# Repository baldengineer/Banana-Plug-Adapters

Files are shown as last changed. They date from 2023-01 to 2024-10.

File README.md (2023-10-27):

Banana jack (4mm, 19mm) to USB-A Adapter Banana (4mm) to USB-A

These adpaters let you plug common power types into a bench power supply. They require a little bit of caution on your side. For example, don't apply 9 volts to the USB adapter!

Each adapter is two pieces made from a single PCB. The part that holds the banana plugs inserts into the adapter part. Then you solder them together. 

## To use them.
* One pack of [Ponoma 72918 4mm banana plug](https://octopart.com/72918-pomona+electronics-585505?r=sp). 
* Break off the two M3 holes
* Use the tabs to solder them together at 90 degrees
* Optional, add LED with current limiting resistor. 
* Optional, clamping diode.
* Plug into power supply. :)

## Discuss on Discord
Join the [AddOhms/Baldengineer Discord](https://discord.gg/Q3xzyuWqm6) to discuss this project.

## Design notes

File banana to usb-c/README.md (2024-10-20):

# Banana Plug to USB-C (Power Only) Adapter

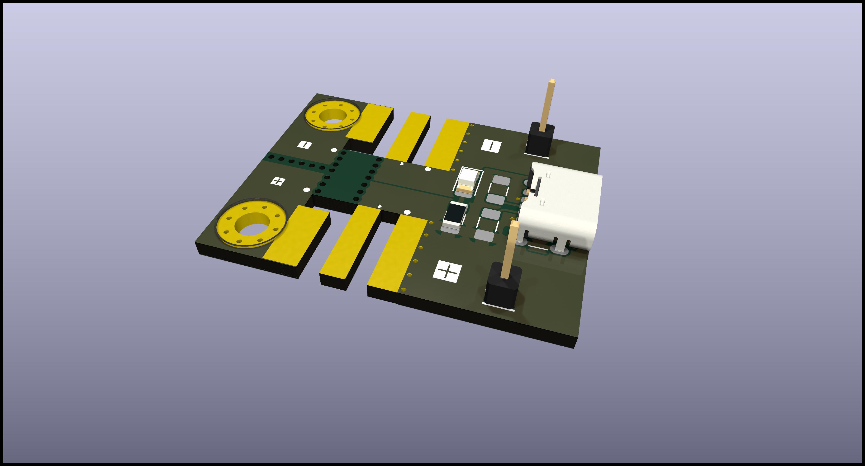
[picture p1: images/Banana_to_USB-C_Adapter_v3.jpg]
usb-c v3


Based on the `USB4125-GF-A` 6 position surface mount connector.

## Version 3: DFP Fix
Version 2 had placements for pull-down resistors. As the DFP, this board should have pull-up resistors. Turns out, most UFP devices don't care so v2 works fine in most cases.

### Status
2024-OCT-20: V3 has not been tested yet.

## DFP Pull-Up Values
| **DFP Advertisement** | **R Pull-Up to 4.75 - 5.5 V** | **R Pull-Up to 3.3 ±5%** |
| :--- | :---: | :---: |
| **Default USB PWR** | 56 kΩ ± 20% | 36 kΩ ± 20% |
| **1.5 A at 5 V** | 22 kΩ ± 5%  | 12 kΩ ± 5% |
| **3.0 A at 5V** | 10 kΩ ± 5% | 4.7 kΩ ± 5% |

[Values from Infineon KB Article](https://community.infineon.com/t5/Knowledge-Base-Articles/USB-Type-C-connector-Rp-Rd-and-Ra-termination-resistors/ta-p/253544)

## Discuss on Discord
Join the [AddOhms/Baldengineer Discord](https://discord.gg/Q3xzyuWqm6) to discuss this project

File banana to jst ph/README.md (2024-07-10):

Banana Plug to JST PH Adapter

This adapter is intended to support Adafruit-style LiPo battery connections for use on a SMU or electronic load.

(You could probably also use the adapter to recondition a LiPo below its minimum safe voltage.)

## PCB Status
Work in-progress: waiting for board to come back from fab.

## Discuss on Discord
Join the [AddOhms/Baldengineer Discord](https://discord.gg/Q3xzyuWqm6) to discuss this project

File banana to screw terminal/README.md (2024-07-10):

Banana Plug to Screw Terminal Adapter Adapter

Based on a (mostly) generic 5.08mm pitch screw terminal

## Discuss on Discord
Join the [AddOhms/Baldengineer Discord](https://discord.gg/Q3xzyuWqm6) to discuss this project

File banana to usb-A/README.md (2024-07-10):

Banana jack (4mm, 19mm) to USB-A Adapter Banana (4mm) to USB-A

## Banana to USB-A Adapter
* Connect USB-A devices to a bench power supply.
* Intended to be used with [Ponoma 72918 banana plug](https://octopart.com/72918-pomona+electronics-585505?r=sp). Break off the two M3 holes, use the tabs to solder them together at 90 degrees, and plug into power supply.
* Rev 1 project link on [OSH Park](https://oshpark.com/shared_projects/gjQOWRep).
* Rev 2 project link on [OSH Park](https://oshpark.com/shared_projects/TIto0uSf).

See root page for instructions on how to use them.

## Discuss on Discord
Join the [AddOhms/Baldengineer Discord](https://discord.gg/Q3xzyuWqm6) to discuss this project

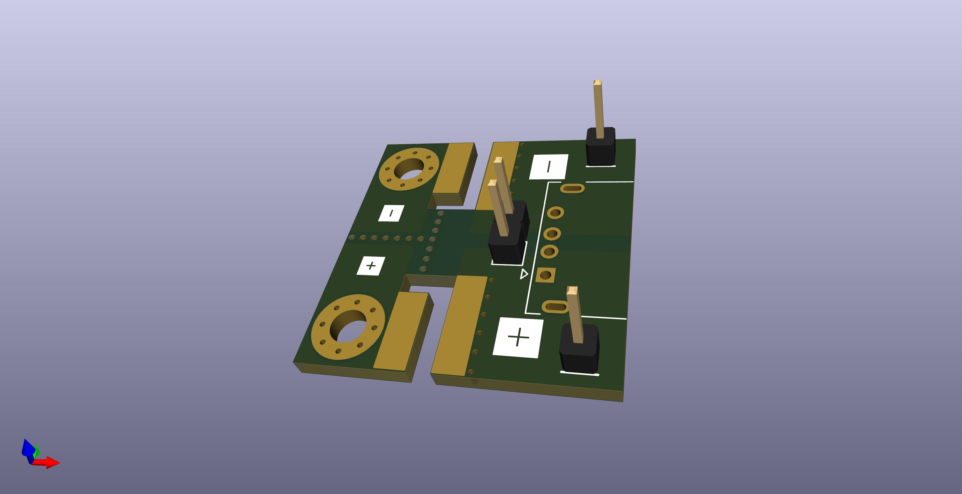
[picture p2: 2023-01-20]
images/Banana_to_USB_Adapter_rev1.jpg

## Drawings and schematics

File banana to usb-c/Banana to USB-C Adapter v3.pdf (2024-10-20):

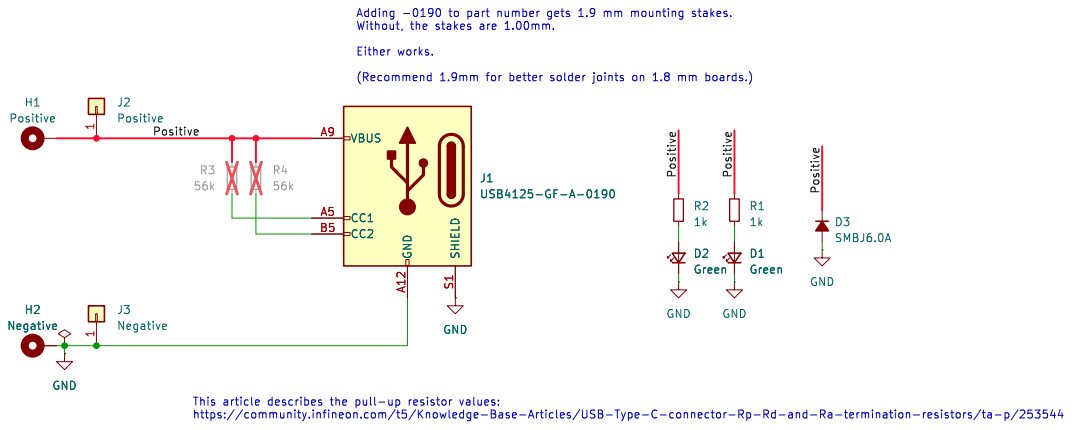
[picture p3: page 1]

Id: 1/1 Title: Banana to USB-C Adapter (Power Only) File: Banana to USB-C Adapter v3.kicad_sch Sheet: / baldengineer.com

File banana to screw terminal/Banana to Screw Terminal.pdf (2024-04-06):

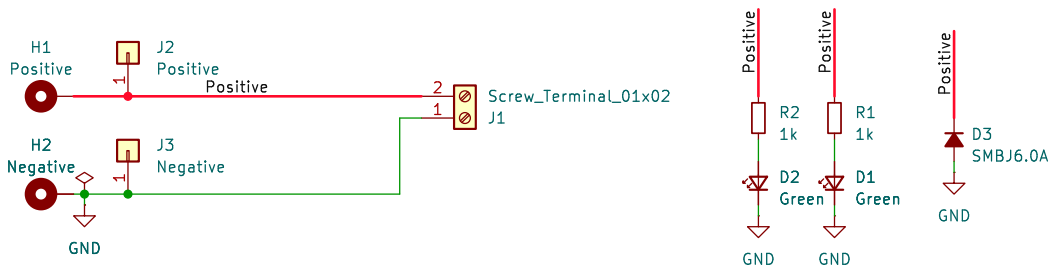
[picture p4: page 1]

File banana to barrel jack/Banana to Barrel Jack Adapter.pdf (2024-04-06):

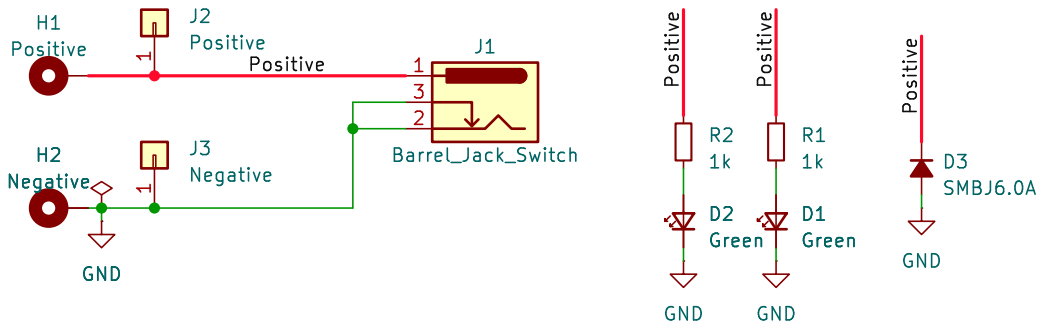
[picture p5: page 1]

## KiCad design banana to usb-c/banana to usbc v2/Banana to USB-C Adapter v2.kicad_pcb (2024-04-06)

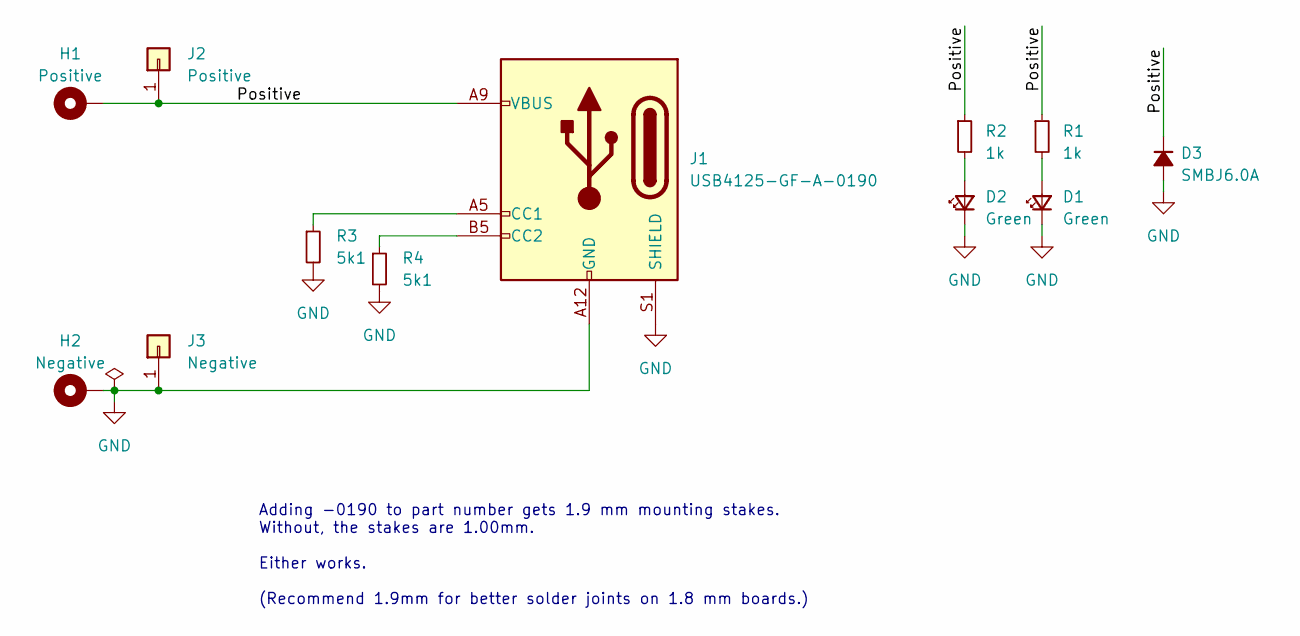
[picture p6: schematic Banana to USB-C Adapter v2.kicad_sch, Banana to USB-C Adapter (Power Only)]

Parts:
D1, D2: Green; LED_1206_3216Metric_Pad1.42x1.75mm_HandSolder
D3: SMBJ6.0A; D_SMA-SMB_Universal_Handsoldering
H1: Positive; MountingHole_3.2mm_M3_Pad_Via
H2: Negative; MountingHole_3.2mm_M3_Pad_Via
J1: USB4125-GF-A-0190; USB_C_Receptacle_GCT_USB4125-xx-x_6P_TopMnt_Horizontal
J2: Positive; PinHeader_1x01_P2.54mm_Vertical
J3: Negative; PinHeader_1x01_P2.54mm_Vertical
R1, R2: 1k; R_1206_3216Metric_Pad1.30x1.75mm_HandSolder
R3, R4: 5k1; R_1206_3216Metric_Pad1.30x1.75mm_HandSolder

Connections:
/Positive: D3.1 (K), H1.1, J1.A9 (VBUS), J1.B9 (VBUS), J2.1, R1.1, R2.1
GND: D1.1 (K), D2.1 (K), D3.2 (A), H2.1, J1.A12 (GND), J1.B12 (GND), J1.S1 (SHIELD), J3.1, R3.2, R4.2
unnamed: D1.2 (A), R1.2
unnamed: D2.2 (A), R2.2
unnamed: J1.A5 (CC1), R3.1
unnamed: J1.B5 (CC2), R4.1

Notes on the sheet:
Adding -0190 to part number gets 1.9 mm mounting stakes. Without, the stakes are 1.00mm. Either works. (Recommend 1.9mm for better solder joints on 1.8 mm boards.)

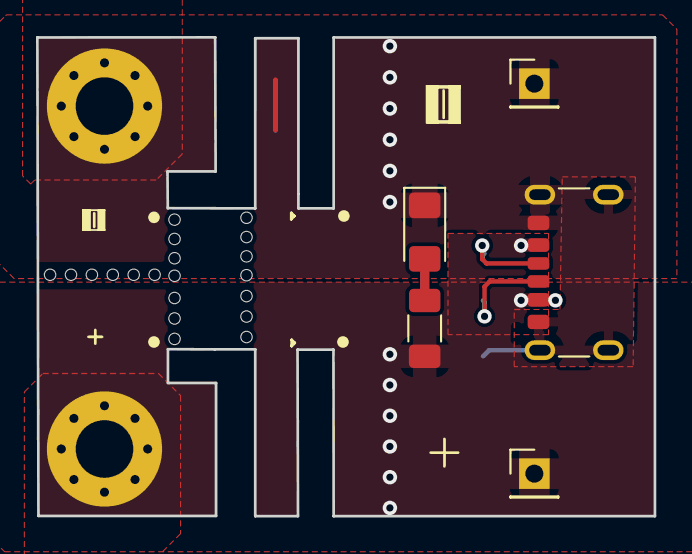
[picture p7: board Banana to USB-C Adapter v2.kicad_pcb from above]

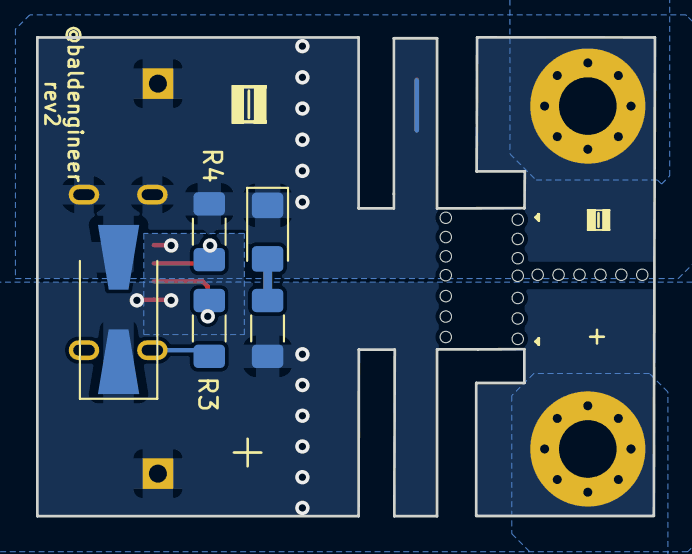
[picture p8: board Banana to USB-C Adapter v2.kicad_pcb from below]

Board: 2 copper layers, 34.3 x 26.6 mm, 12 parts (5 on the bottom side), 6 nets.

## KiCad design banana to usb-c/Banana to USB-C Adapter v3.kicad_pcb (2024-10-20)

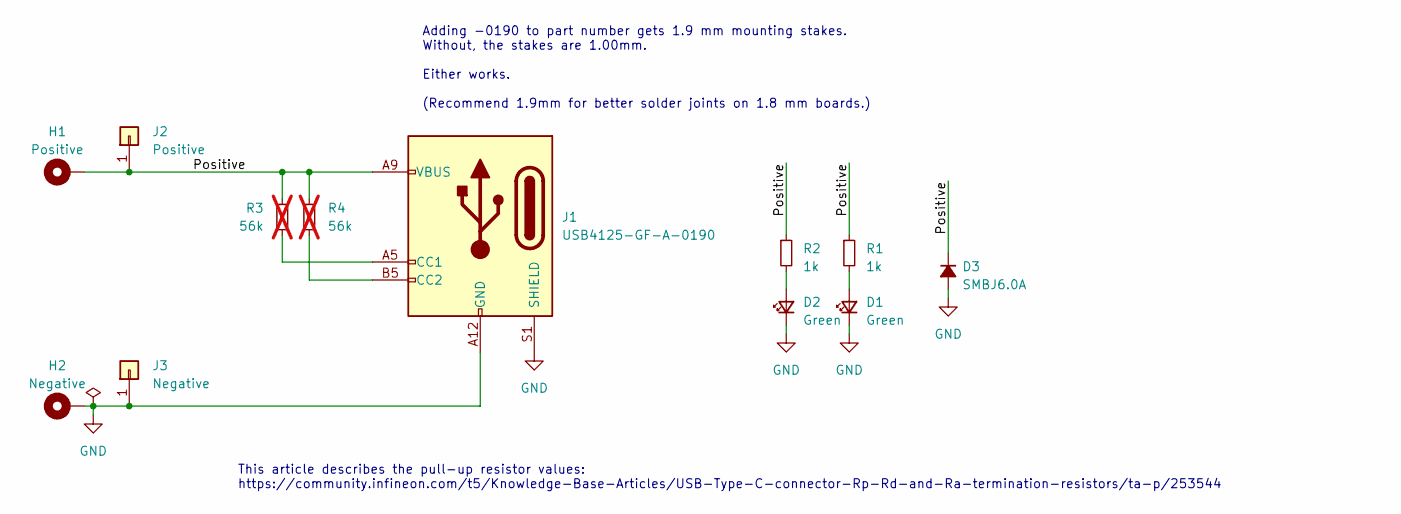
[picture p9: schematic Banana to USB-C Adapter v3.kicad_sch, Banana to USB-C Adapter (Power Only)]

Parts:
D1, D2: Green; LED_1206_3216Metric_Pad1.42x1.75mm_HandSolder
D3: SMBJ6.0A; D_SMA-SMB_Universal_Handsoldering
H1: Positive; MountingHole_3.2mm_M3_Pad_Via
H2: Negative; MountingHole_3.2mm_M3_Pad_Via
J1: USB4125-GF-A-0190; USB_C_Receptacle_GCT_USB4125-xx-x_6P_TopMnt_Horizontal
J2: Positive; PinHeader_1x01_P2.54mm_Vertical
J3: Negative; PinHeader_1x01_P2.54mm_Vertical
R1, R2: 1k; R_1206_3216Metric_Pad1.30x1.75mm_HandSolder
R3, R4: 56k; R_1206_3216Metric_Pad1.30x1.75mm_HandSolder; not fitted

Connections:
/Positive: D3.1 (K), H1.1, J1.A9 (VBUS), J1.B9 (VBUS), J2.1, R1.1, R2.1, R3.1, R4.1
GND: D1.1 (K), D2.1 (K), D3.2 (A), H2.1, J1.A12 (GND), J1.B12 (GND), J1.S1 (SHIELD), J3.1
unnamed: D1.2 (A), R1.2
unnamed: D2.2 (A), R2.2
unnamed: J1.A5 (CC1), R3.2
unnamed: J1.B5 (CC2), R4.2

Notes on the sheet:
Adding -0190 to part number gets 1.9 mm mounting stakes. Without, the stakes are 1.00mm. Either works. (Recommend 1.9mm for better solder joints on 1.8 mm boards.)
This article describes the pull-up resistor values: https://community.infineon.com/t5/Knowledge-Base-Articles/USB-Type-C-connector-Rp-Rd-and-Ra-termination-resistors/ta-p/253544

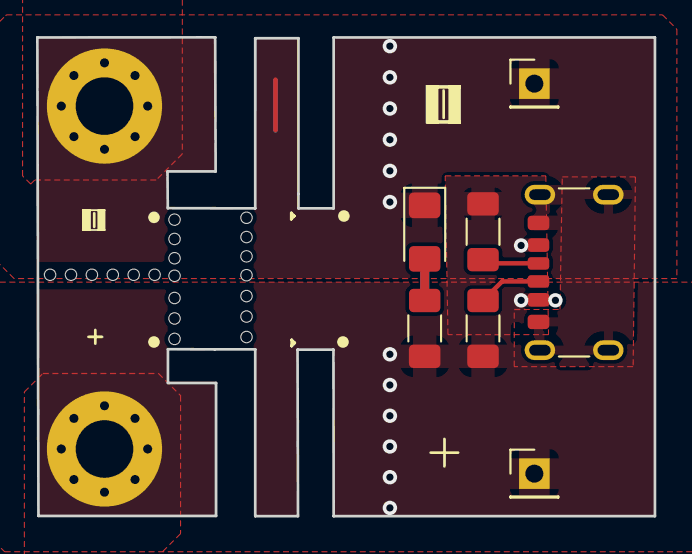
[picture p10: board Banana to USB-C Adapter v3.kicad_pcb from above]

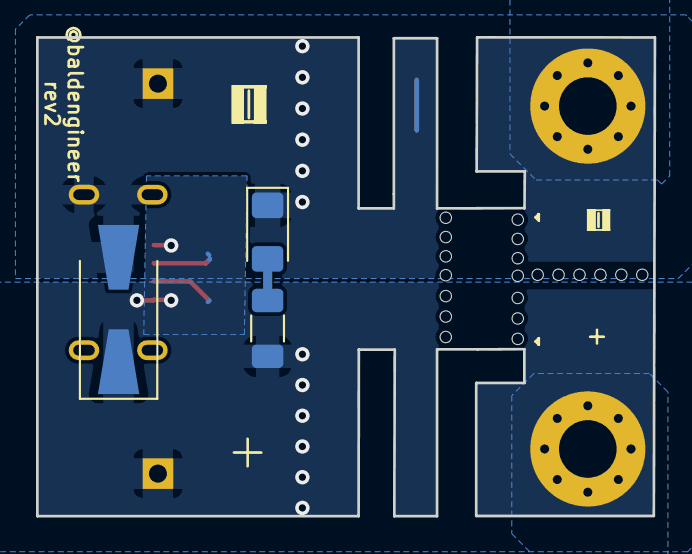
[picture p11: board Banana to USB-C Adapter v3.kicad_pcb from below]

Board: 2 copper layers, 34.3 x 26.6 mm, 12 parts (3 on the bottom side), 6 nets.

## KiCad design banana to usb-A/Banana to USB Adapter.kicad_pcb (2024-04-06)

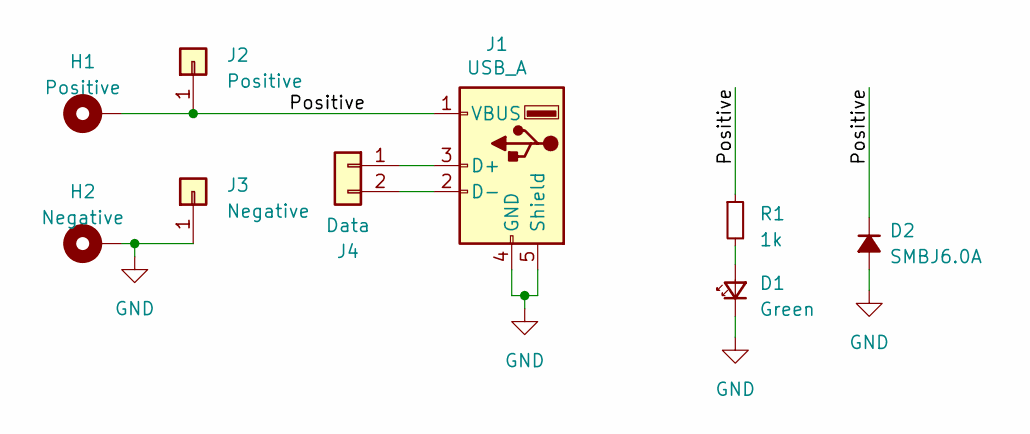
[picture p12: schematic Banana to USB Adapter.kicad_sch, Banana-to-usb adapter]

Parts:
D1: Green; LED_1206_3216Metric_Pad1.42x1.75mm_HandSolder
D2: SMBJ6.0A; D_SMA-SMB_Universal_Handsoldering
H1: Positive; MountingHole_3.2mm_M3_Pad_Via
H2: Negative; MountingHole_3.2mm_M3_Pad_Via
J1: USB_A; USB_A_GCT_USB1125; MPN USB1125-GF-B
J2: Positive; PinHeader_1x01_P2.54mm_Vertical
J3: Negative; PinHeader_1x01_P2.54mm_Vertical
J4: Data; PinHeader_1x02_P2.54mm_Vertical
R1: 1k; R_1206_3216Metric_Pad1.30x1.75mm_HandSolder

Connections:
/Positive: D2.1 (K), H1.1, J1.1 (VBUS), J2.1, R1.1
GND: D1.1 (K), D2.2 (A), H2.1, J1.4 (GND), J1.5 (Shield), J3.1
unnamed: D1.2 (A), R1.2
unnamed: J1.3 (D+), J4.1
unnamed: J1.2 (D-), J4.2

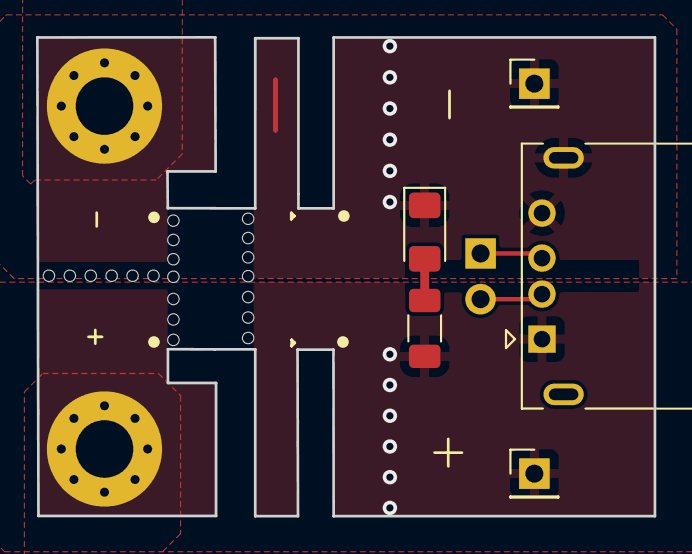
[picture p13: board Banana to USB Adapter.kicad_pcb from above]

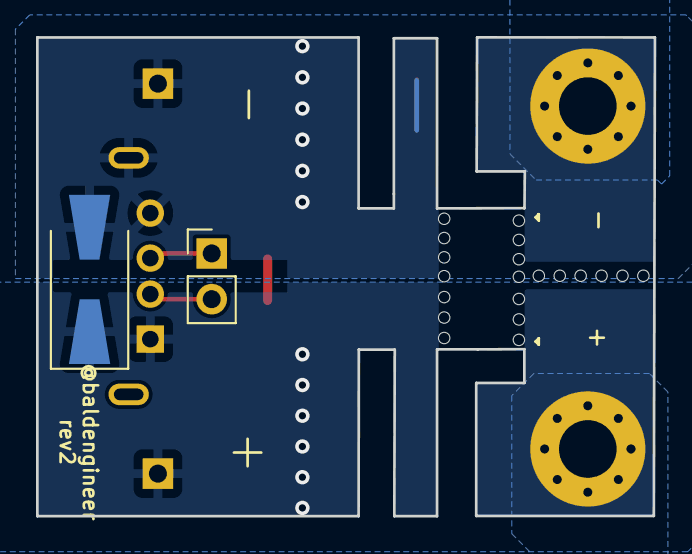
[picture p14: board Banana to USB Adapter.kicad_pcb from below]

Board: 2 copper layers, 34.3 x 26.6 mm, 9 parts (2 on the bottom side), 5 nets.

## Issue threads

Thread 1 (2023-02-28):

R1: +V and GND are backwards

baldengineer, 2023-02-28:
Minor important, but the nodes for +V and GND are backward on the Host (USB-A) connector.

¯\_(ツ)_/¯

baldengineer, 2023-02-28:
Actually... the PCB is fine. There's an issue with assembly, will open new issue.

Closed 2023-02-28.

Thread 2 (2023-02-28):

R1: Need to extend pads

baldengineer, 2023-02-28:
The pads on the screw hole side should be extended. That way, both the top and bottom can be soldered.

Right now, the solder only joins the top pads, which creates a lever point.

baldengineer, 2023-03-04:
Made some changes to the pads, but I think moving the mouse bite (#2) to a new location will provided the needed offsets.

Closed 2023-03-04.

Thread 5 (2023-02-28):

R1: Indicate on silk orientation of pieces

baldengineer, 2023-02-28:
Initially, as stated in #1, I thought there was a PCB issue. When assembling, it is possible to bring the two pieces together in a way that reverses +5V and GND.

That's not so good.

Add silk screen dots or something to indicate which sides should come together. Or at least makes it very clear where the USB-A goes.

Closed 2023-03-04.

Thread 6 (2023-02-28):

R1: Reuce thermal pads on the screw holes

baldengineer, 2023-02-28:
There is very little copper connecting the screw holes. No need fo rthermal relief there.

baldengineer, 2023-03-04:
Made some changes to the pads, but I like moving the mouse bite to a new location will provided the needed offsets.

Closed 2023-03-04.

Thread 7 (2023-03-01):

R1: Add crowbar diode for additional protection

baldengineer, 2023-03-01:
Provide some over-voltage and reverse polarity protection.

At a min, add footprints for it.

(Gough suggested a SMBJ6.0A)

Closed 2023-03-04.

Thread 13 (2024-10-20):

usb-c has placements for ufp resistors

baldengineer, 2024-10-20:
The USB-C v2 adapter has pull-down resistor pads.

These should be a pull-up for a DFP adapter.

(UFP is the device side, and DFP is the "host" side.)

baldengineer, 2024-10-20:
Fixed with #14

baldengineer, 2024-10-20:
Fixed with #14

Closed 2024-10-20.

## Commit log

2023-01-20 rev 1 submitted to fab
    [Banana to USB Adapter.kicad_pcb, Banana to USB Adapter.kicad_sch]
2023-03-03 rev2 addresses #2, #3, #5, #6, #7
    [Banana to USB Adapter.kicad_pcb, Banana to USB Adapter.kicad_sch]
2023-03-03 rev1 gerbs
    [Banana to USB Adapter-B_Cu.gbr, Banana to USB Adapter-B_Mask.gbr, Banana to USB Adapter-B_Paste.gbr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]
2023-03-03 rev2 as submitted to fab
    [Banana to USB Adapter.kicad_pcb]
2023-03-03 rev2 gerbs
    [Banana to USB Adapter-B_Cu.gbr, Banana to USB Adapter-B_Mask.gbr, Banana to USB Adapter-B_Paste.gbr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]
2023-10-27 rev2 and renaming directories for other adapters
    [Banana to Barrel Jack Adapter.kicad_pcb, Banana to Barrel Jack Adapter.kicad_sch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]
2023-10-27 more name changes
    [Banana to Barrel Jack Adapter.kicad_pcb, Banana to Barrel Jack Adapter.kicad_sch, Banana to USB Adapter.kicad_pcb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]
2023-11-21 No design changes to PCB. Removed extra LED reference in schematic, changed TVS diode to D2, and uploaded PCB.
    [Banana to USB Adapter.kicad_pcb, Banana to USB Adapter.kicad_sch]
2024-03-14 kicad8 upgrade
    [Banana to USB Adapter.kicad_pcb]
2024-04-04 DRC is giving off-grid errors and "GND modified"
    [Banana to Barrel Jack Adapter.kicad_sch]
2024-04-04 Cleared DRC issues
    [Banana to Barrel Jack Adapter.kicad_pcb, Banana to Barrel Jack Adapter.kicad_sch]
2024-04-04 Zone Relief DRC error in PCB
    [Banana to Barrel Jack Adapter.kicad_pcb]
2024-04-04 0 DRC before changing zones for positive
    [Banana to Barrel Jack Adapter.kicad_pcb]
2024-04-04 DRC warning about footprints not matching library. going to try and update all.
    [Banana to Barrel Jack Adapter.kicad_pcb]
2024-04-04 passing DRC but lost the breakaway holes for the banana plugs
    [Banana to Barrel Jack Adapter.kicad_pcb]
2024-04-06 put missing drill holes back! (and locked them
    [Banana to USB Adapter.kicad_pcb]
2024-04-06 fixed missing drill holes
    [Banana to Barrel Jack Adapter.kicad_pcb]
2024-04-06 barrel jack gerbs (and schematic pdf) ready for fab.
    [Banana to Barrel Jack Adapter-B_Cu.gbr, Banana to Barrel Jack Adapter-B_Mask.gbr, Banana to Barrel Jack Adapter-B_Paste.gbr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]
2024-04-06 initial schematic (pcb is still barrel jack)
    [Banana to USB-C Adapter.kicad_pcb, Banana to USB-C Adapter.kicad_sch]
2024-04-06 pcb updated with usb-c components, 7 unrouted. yikes.
    [Banana to USB-C Adapter.kicad_pcb]
2024-04-06 usb-c ready for fab
    [Banana to USB-C Adapter-B_Cu.gbr, Banana to USB-C Adapter-B_Mask.gbr, Banana to USB-C Adapter-B_Paste.gbr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]
2024-04-06 screw terminal 5.08mm adapter
    [Banana to Screw Terminal-B_Cu.gbr, Banana to Screw Terminal-B_Mask.gbr, Banana to Screw Terminal-B_Paste.gbr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]
2024-07-10 initial jst ph commit
    [banana to jst ph.kicad_pcb, banana to jst ph.kicad_sch]
2024-07-10 updated schematic but need to verify pin 1 and 2 connections
    [banana to jst ph.kicad_pcb, banana to jst ph.kicad_sch]
2024-07-10 jst ph sm4 adapter rev 2 ready for fab
    [banana to jst ph-B_Cu.gbr, banana to jst ph-B_Mask.gbr, banana to jst ph-B_Paste.gbr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]
2024-07-10 Changing gerb folder name
    [banana to jst ph-B_Cu.gbr, banana to jst ph-B_Mask.gbr, banana to jst ph-B_Paste.gbr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]
2024-07-10 added SPN for JST
    [banana to jst ph.kicad_sch]
2024-10-20 inital usb-c rev3 create
    [Banana to USB-C Adapter v2.kicad_pcb, Banana to USB-C Adapter v2.kicad_sch, Banana to USB-C Adapter v3.kicad_pcb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]
2024-10-20 sch: changed resistors to pull-up and added link to kb article
    [Banana to USB-C Adapter v3.kicad_pcb, Banana to USB-C Adapter v3.kicad_sch]
2024-10-20 updated usbc pcb, generated v3 gerbs
    [Banana to USB-C Adapter v3-B_Cu.gbr, Banana to USB-C Adapter v3-B_Mask.gbr, Banana to USB-C Adapter v3-B_Paste.gbr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]
